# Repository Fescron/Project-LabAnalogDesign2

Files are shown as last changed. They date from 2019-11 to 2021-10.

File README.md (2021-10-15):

# Project-LabAnalogDesign2






<br/>

The goal of this lab was to design a 5 - 9V to 3,3V (500 mA min) buck converter from the ground up. We had to start from a given chip (`RT8259GE`) and create the rest ourselves.

Careful layout considerations were taken to lead to an optimal design. The `0Ω` resistor is not on the schematic but only on the board layout. It's footprint was used to *jump* over the feedback track so everything is on the top layer. A via to GND is placed around it as well for redundancy.

- `JP1` can be used to disable the buck converter.
- `JP2` can be used to bypass the sense resistor `R3` (measures the diode current).
- A lot of test points (`TPx`) are given to be able to measure different voltages.
- `C4` and `C5` are footprints for extra capacitors if the signals have too much ripple.
<!-- fix vertical spacing -->
- VIN: 4,5 - 24 V
- VOUT: 3,3 V @ 1,2 A max
<!-- fix vertical spacing -->
- Click [here](hardware/dc-dc-3-3V-RT8259GE/dc-dc-3-3V-RT8259GE.pdf) to go to the **schematic**.
- Click [here](documentation/report/AnaloogOntwerp2-Labo-BuckConverter-Brecht-Arno.pdf) to go to the **report** (Dutch).

<br/>

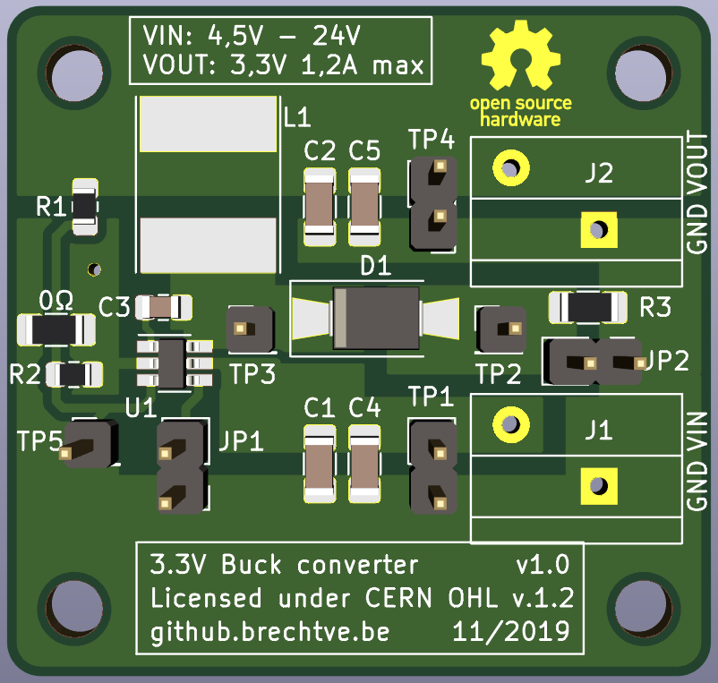
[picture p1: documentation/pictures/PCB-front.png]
PCB front
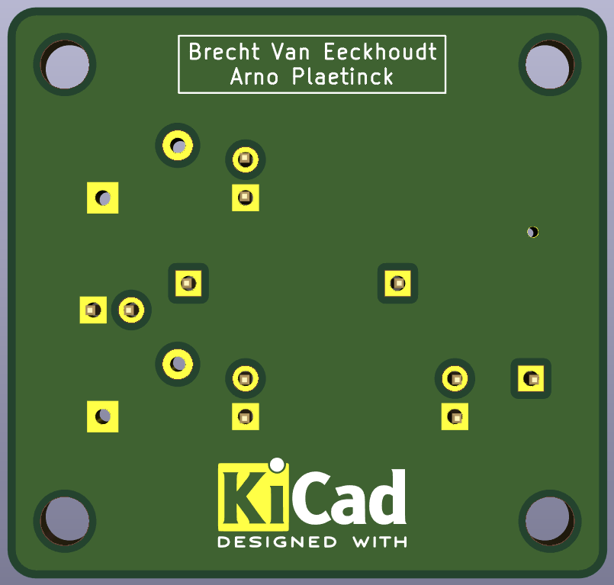
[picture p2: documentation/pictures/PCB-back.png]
PCB back
 &nbsp; &nbsp; 

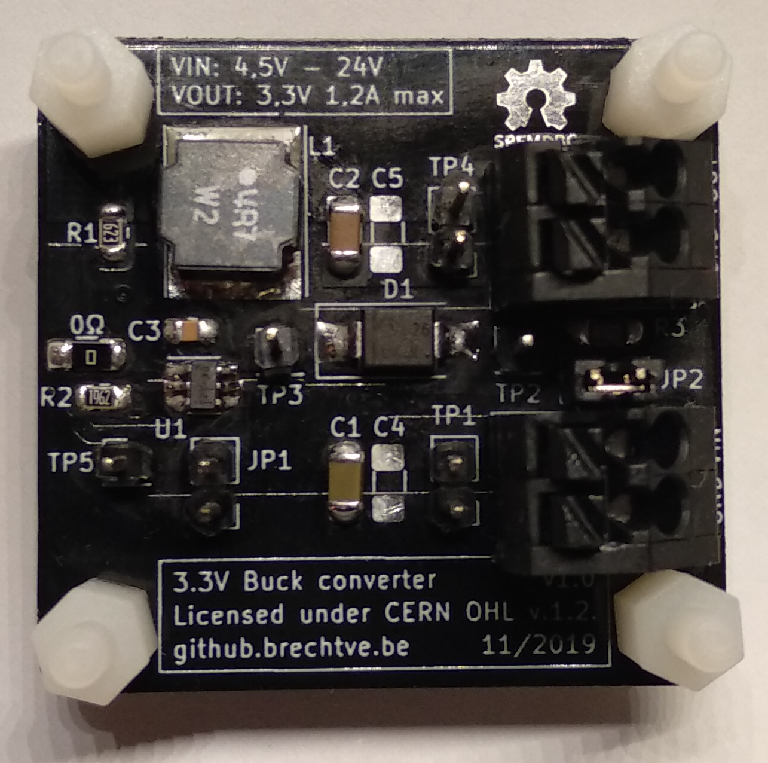
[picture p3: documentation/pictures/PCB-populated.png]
PCB populated


<br/>

## BOM

| Component | Value | Footprint | Other | Ordering |
| --- | --- | --- | --- | --- |
| U1 | RT8259GE | SOT-23-6 | Richtek | |
| C1, C4 | 10 µF | 1206 | (X7R), 50V, 10% | [Mouser.be](https://www.mouser.be/ProductDetail/Taiyo-Yuden/UMK316BBJ106KL-T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) |
| C2, C5 | 22 µF | 1206 | X7R, 10V, 10% | [Mouser.be](https://www.mouser.be/ProductDetail/Taiyo-Yuden/LMK316AB7226KL-TR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) |
| C3 | 10 nF = 0,01 µF | 0805 | X7R, 50V, 10% | [Mouser.be](https://www.mouser.be/ProductDetail/Wurth-Elektronik/885012207092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) |
| D1 | If = 2A Vr = 40V Vf = 0,43V | SMA/SMB | | [Mouser.be](https://www.mouser.be/ProductDetail/ON-Semiconductor/MBRS2040LT3G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) |
| L1 | 4,7 µH | NR8040 | Taiyo Yuden | [Mouser.be](https://www.mouser.be/ProductDetail/Taiyo-Yuden/NR8040T4R7N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) |
| R1 | 62 kΩ | 0805 | 0,5% | [Mouser.be](https://www.mouser.be/ProductDetail/Susumu/RR1220P-623-D?qs=sGAEpiMZZMtlubZbdhIBIIeqUIwQIz3%2F4suNfbqaJx0%3D) |
| R2 | 19,6 kΩ | 0805 | 0,5% | [Mouser.be](https://www.mouser.be/ProductDetail/Susumu/RR1220P-1962-D-M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) |
| R3 | 0,1 Ω = 100 mΩ | 1206 | 1% | [Mouser.be](https://www.mouser.be/ProductDetail/Ohmite/KDV12FR100ET?qs=sGAEpiMZZMtlubZbdhIBIFv9D87cWnlaxTC7ytBtffo%3D) |
| 0Ω | 0 Ω | 1206 | | [Mouser.be](https://www.mouser.be/ProductDetail/Yageo/RC1206JR-070RL?qs=sGAEpiMZZMtlubZbdhIBIMHu9P6GKOabM4IOLvph3MY%3D) |
| J1, J2 | PTSA_1,5/_2-3,5-Z_BK | Pitch: 3,5 mm | 2 contacts, 250V 2A | [Mouser.be](https://www.mouser.be/ProductDetail/Phoenix-Contact/1751765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) |

> **WARNING:** The pinout of J1 and J2 is reversed due to a footprint error (wrong top/bottom view). The Phoenix Contact connectors can however be manually separated and put back together in a way that they do fit on the board.

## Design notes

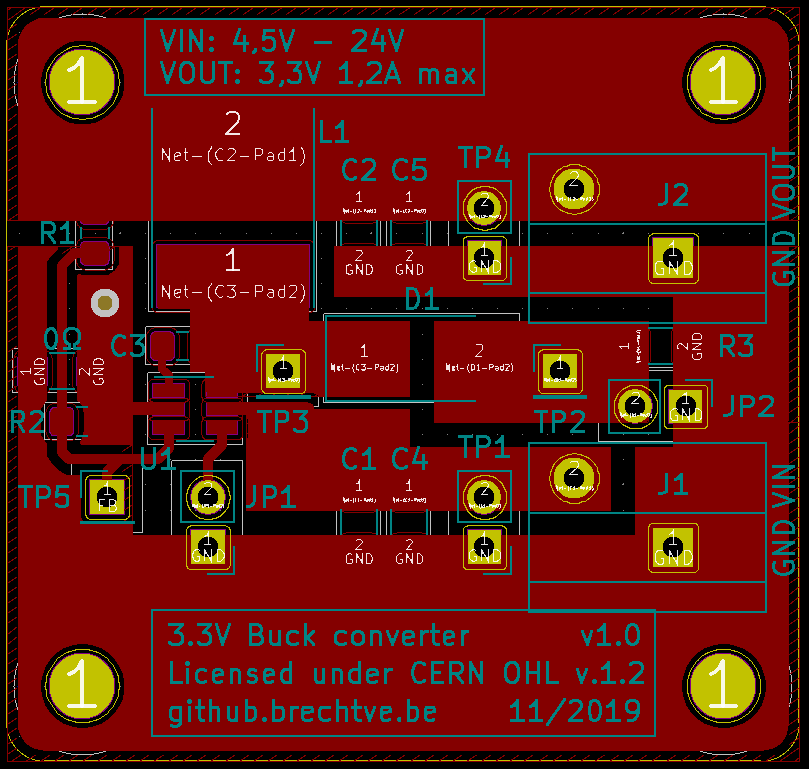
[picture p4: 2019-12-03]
documentation/pictures/PCB.png

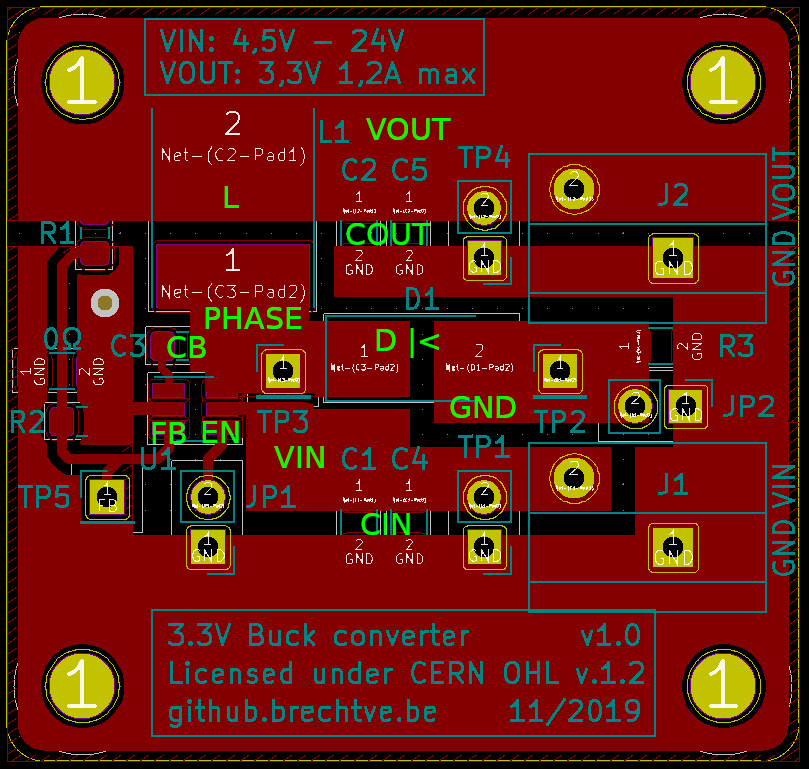
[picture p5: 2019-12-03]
documentation/pictures/PCB-annotated.png

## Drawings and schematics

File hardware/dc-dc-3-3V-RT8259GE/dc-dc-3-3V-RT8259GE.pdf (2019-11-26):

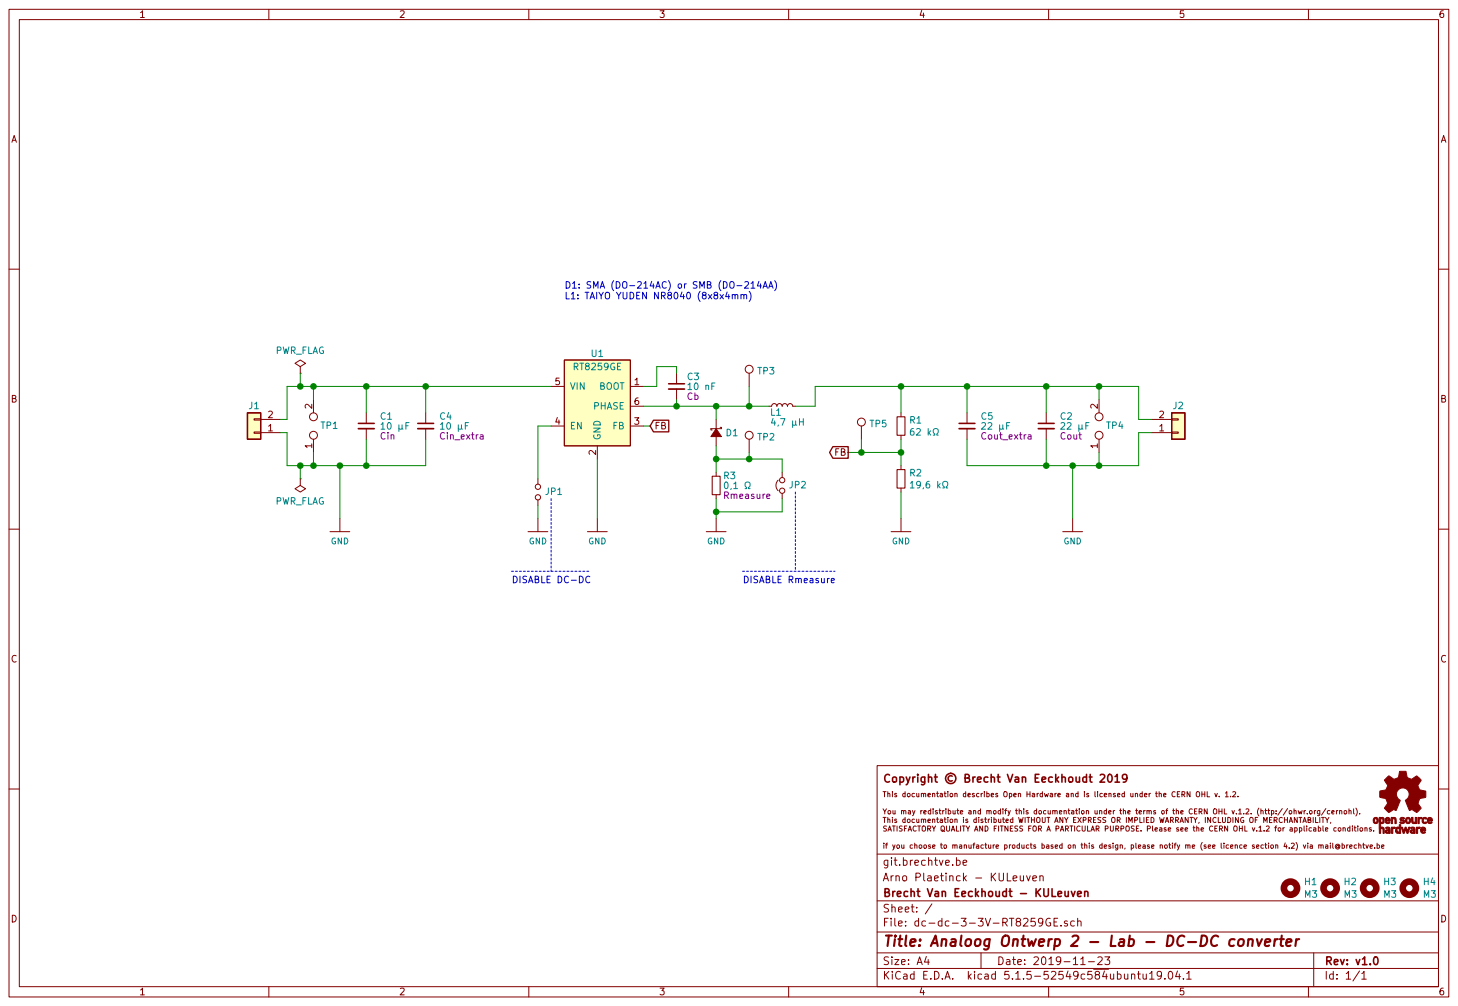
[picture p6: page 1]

FB D1: SMA (DO-214AC) or SMB (DO-214AA)

2 FB 3 EN 4 VIN 5 PHASE 6 U1 RT8259GE H1 M3

Copyright © Brecht Van Eeckhoudt 2019

This documentation describes Open Hardware and is licensed under the CERN OHL v. 1.2.

You may redistribute and modify this documentation under the terms of the CERN OHL v.1.2. (http://ohwr.org/cernohl).

git.brechtve.be
Id: 1/1 Title: Analoog Ontwerp 2 - Lab - DC-DC converter File: dc-dc-3-3V-RT8259GE.sch Sheet: / Brecht Van Eeckhoudt - KULeuven Arno Plaetinck - KULeuven

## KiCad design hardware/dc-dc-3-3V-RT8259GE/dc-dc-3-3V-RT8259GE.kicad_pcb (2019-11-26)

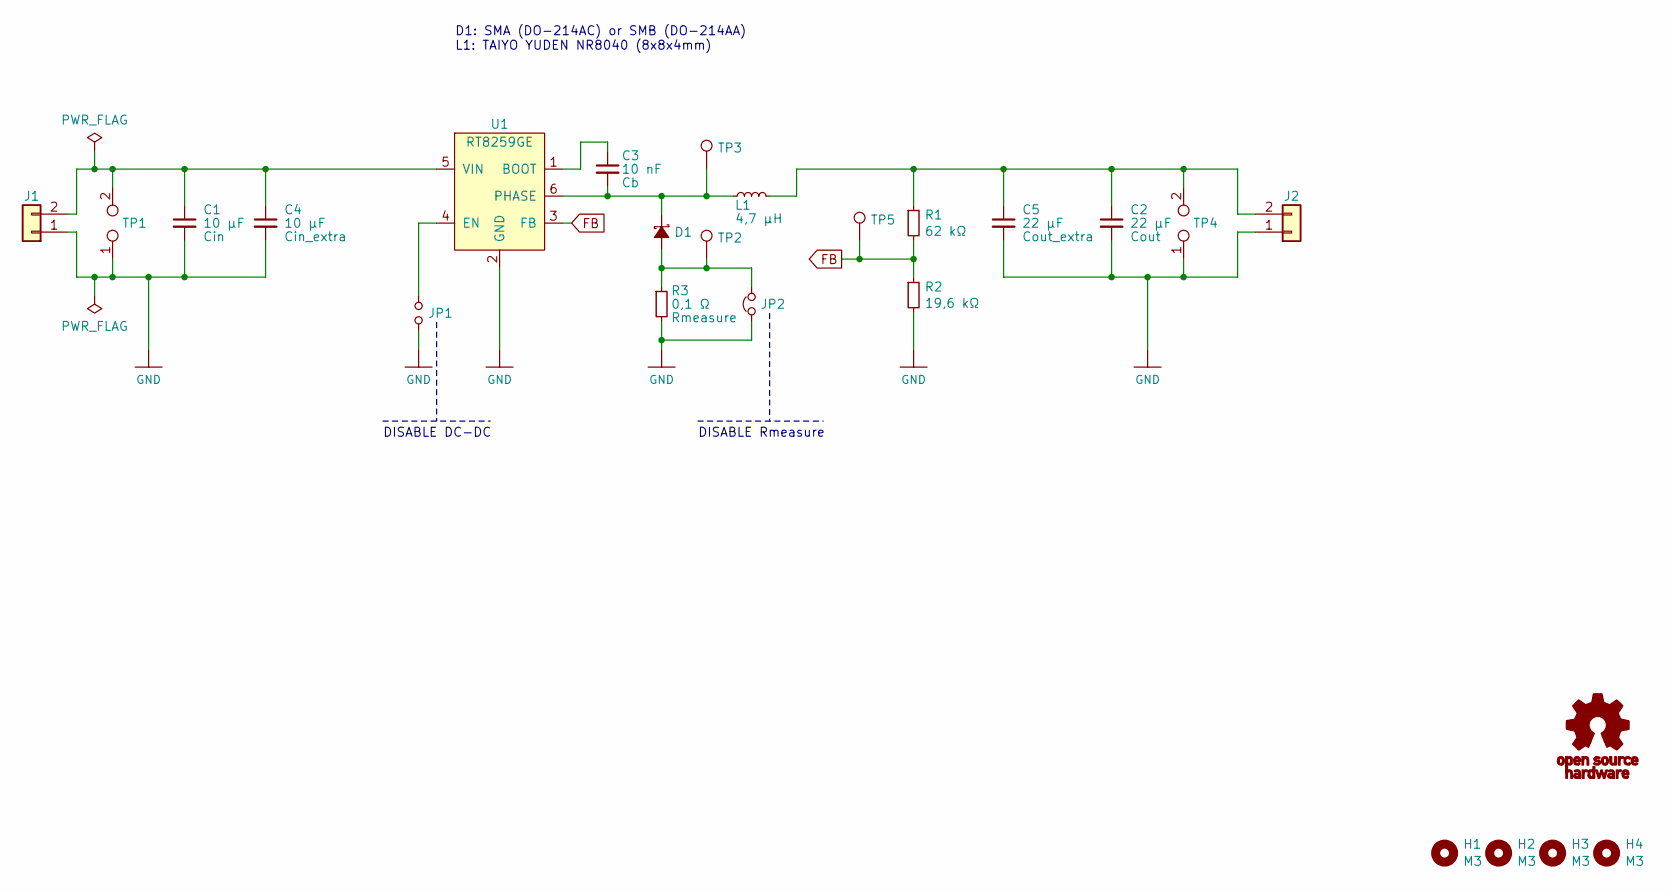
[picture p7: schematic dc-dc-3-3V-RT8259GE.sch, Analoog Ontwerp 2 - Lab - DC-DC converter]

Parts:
C1, C4: 10 µF; C_1206_3216Metric_Pad1.42x1.75mm_HandSolder
C2, C5: 22 µF; C_1206_3216Metric_Pad1.42x1.75mm_HandSolder
C3: 10 nF; C_0805_2012Metric_Pad1.15x1.40mm_HandSolder
D1: D_Schottky_Small_ALT; D_SMA-SMB_Universal_Handsoldering
G1: Symbol_OSHW-EEVBLOG_SPFMDBC_10mm; OSHW-Logo_5.7x6mm_SolderMask
H1, H2, H3, H4: M3; MountingHole_3.2mm_M3
J1, J2: Conn_01x02; PhoenixContact_PTSA_1,5_2-G-3,5_1x02_P3.50mm_Angled
JP1: Jumper_NO_Small; PinHeader_1x02_P2.54mm_Vertical
JP2: Jumper_NC_Small; PinHeader_1x02_P2.54mm_Vertical
L1: 4,7 µH; L_Taiyo-Yuden_NR-80xx_HandSoldering
R1: 62 kΩ; R_0805_2012Metric_Pad1.15x1.40mm_HandSolder
R2: 19,6 kΩ; R_0805_2012Metric_Pad1.15x1.40mm_HandSolder
R3: 0,1 Ω; R_1206_3216Metric_Pad1.42x1.75mm_HandSolder
TP1, TP4: TestPoint_2Pole; PinHeader_1x02_P2.54mm_Vertical
TP2, TP3, TP5: TestPoint; PinHeader_1x01_P2.54mm_Vertical
U1: RT8259GE; SOT-23-6_Handsoldering

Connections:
FB: R1.2, R2.1, TP5.1, U1.3 (FB)
GND: C1.2, C2.2, C4.2, C5.2, J1.1, J2.1, JP1.1, JP2.1, R2.2, R3.2, TP1.1, TP4.1, U1.2 (GND); also elsewhere on the board
unnamed: C1.1, C4.1, J1.2, TP1.2, U1.5 (VIN)
unnamed: C2.1, C5.1, J2.2, L1.2, R1.1, TP4.2
unnamed: C3.1, U1.1 (BOOT)
unnamed: C3.2, D1.1 (K), L1.1, TP3.1, U1.6 (PHASE)
unnamed: D1.2 (A), JP2.2, R3.1, TP2.1
unnamed: JP1.2, U1.4 (EN)

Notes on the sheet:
DISABLE DC-DC
DISABLE Rmeasure
D1: SMA (DO-214AC) or SMB (DO-214AA) L1: TAIYO YUDEN NR8040 (8x8x4mm)

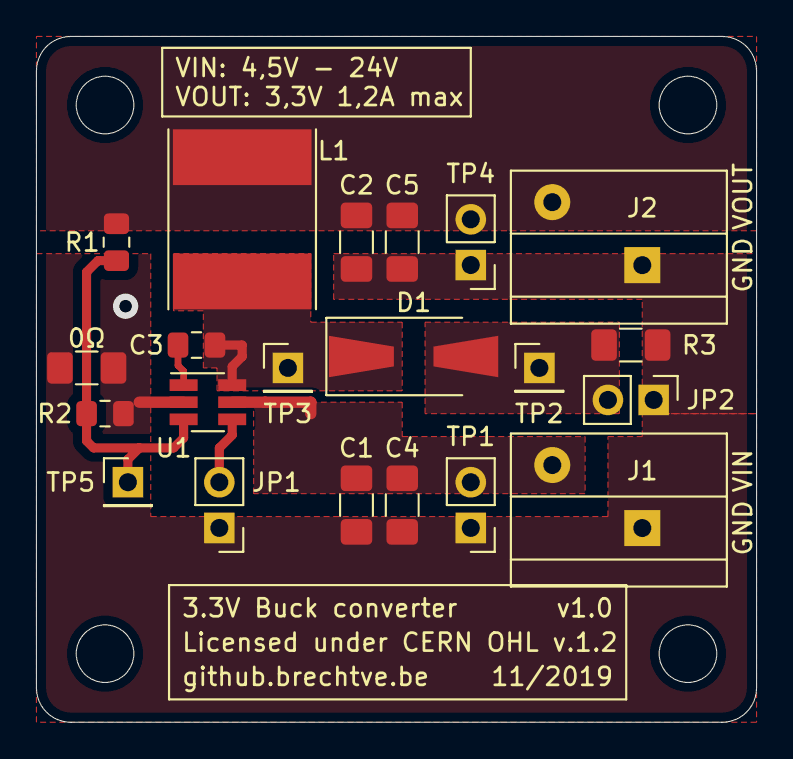
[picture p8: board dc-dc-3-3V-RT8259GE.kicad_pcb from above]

Board: 2 copper layers, 40.0 x 38.1 mm, 26 parts (0 on the bottom side), 8 nets.

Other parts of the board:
0Ω: R_1206_3216Metric_Pad1.42x1.75mm_HandSolder

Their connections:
GND: 0Ω.1, 0Ω.2; also elsewhere on the board

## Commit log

2019-11-26 Added schematic and board layout
    [dc-dc-3-3V-RT8259GE.kicad_pcb, dc-dc-3-3V-RT8259GE.sch]
2019-12-03 Updated readme with note about wrong footprint

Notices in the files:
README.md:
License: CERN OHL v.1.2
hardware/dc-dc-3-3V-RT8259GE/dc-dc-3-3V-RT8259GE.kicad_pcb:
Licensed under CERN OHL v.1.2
